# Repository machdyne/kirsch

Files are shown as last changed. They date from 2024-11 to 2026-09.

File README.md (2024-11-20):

# Kirsch Computer

Kirsch is an FPGA computer designed by Lone Dynamics Corporation.

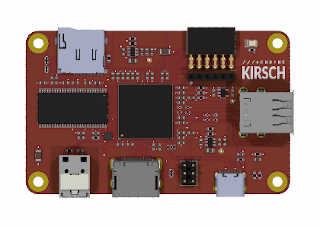
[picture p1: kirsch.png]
Kirsch Computer


This repo will contain schematics, PCB layouts, pinouts, a 3D-printable case, example gateware and documentation.

Find more information on the [Kirsch product page](https://machdyne.com/product/kirsch-computer/).

## Programming Kirsch

Kirsch has a JTAG interface that can be used to program the SRAM or the included flash [MMOD](https://machdyne.com/product/mmod).

### JTAG

These examples assume you're using a "USB Blaster" JTAG cable, see the header pinout below. You will need to have [openFPGALoader](https://github.com/trabucayre/openFPGALoader) installed.

Program the configuration SRAM:

```
openFPGALoader -c usb-blaster blinky.bit
```

Program the flash MMOD:

```
openFPGALoader -f -c usb-blaster blinky.bit --fpga-part xc7a35tftg256
```

## Blinky 

Building the blinky example requires Vivado or [openxc7](https://github.com/openxc7).

Assuming they are installed, you can simply type `make blinky_openxc7` or `make blinky_vivado` to build the gateware, which will be written to output/blinky.bit. You can then use [openFPGALoader](https://github.com/trabucayre/openFPGALoader) to write the gateware to the device.

## Linux

See the [Kakao Linux](https://github.com/machdyne/kakao) repo for the latest instructions.

### Prebuilt Images

Copy the files from the `images/linux` and `images/v0` directory to the root directory of a FAT-formatted MicroSD card along with the files from the `images` directory in the [Kakao Linux](https://github.com/machdyne/kakao) repo.

Kirsch ships with LiteX gateware on the user gateware section of the MMOD that is compatible with these images. After several seconds the Linux penguin should appear on the screen (HDMI) followed by a login prompt. A serial console is also available over the USB-C port.

**Note: If using the `kirsch_usbacm.bit` bitstream, Kirsch won't boot until you've opened a terminal program on the correct port. This is because DTR is currently used as a reset signal (see [valentyusb](https://github.com/litex-hub/valentyusb)). If you want to use Kirsch standalone, use `kirsch.bit` instead which uses the PMOD as a serial console.**

### Building Linux

Please follow the setup instructions in the [linux-on-litex-vexriscv](https://github.com/litex-hub/linux-on-litex-vexriscv) repo and then:

1. Build the Linux-capable gateware:

```
$ cd linux-on-litex-vexriscv
$ ./make.py --board kirsch --build
```

2. Write the gateware to the MMOD using USB DFU:

```
$ openFPGALoader -f -c usb-blaster build/kirsch/gateware/kirsch.bit --fpga-part xc7a35tftg256 
```
3. Copy the device tree binary `build/kirsch/kirsch.dtb` to a FAT-formatted MicroSD card.

4. Build the Linux kernel and root filesystem:

See the [Kakao Linux](https://github.com/machdyne/kakao?tab=readme-ov-file#optional-building-kakao-linux) repo for instructions.

5. Copy the Image and rootfs.cpio files generated in the previous step to the boot partition of the MicroSD card, in addition to the following files:

6. Copy the OpenSBI binary (included in this repo as `kirsch/images/linux/opensbi.bin`) to the MicroSD card. Alternatively, you can build this binary by following [these instructions](https://github.com/litex-hub/linux-on-litex-vexriscv#-generating-the-opensbi-binary-optional).

7. Copy `kirsch/images/linux/boot.json` to the MicroSD card.

8. Power-cycle Kirsch. After Linux has finished booting you should see a login prompt on the HDMI display.

## JTAG Header

The 3.3V JTAG header can be used to program the FPGA SRAM as well as the MMOD flash memory. It can also be used to provide power (5V) to the board.

```
1 2
3 4
5 6
```

| Pin | Signal |
| --- | --- |
| 1 | TCK |
| 2 | TDI |
| 3 | TDO |
| 4 | TMS |
| 5 | 5V0 |
| 6 | GND |

## Board Revisions

| Revision | Notes |
| --- | ----- |
| V0 | Initial version |

## License

The contents of this repo are released under the [Lone Dynamics Open License](LICENSE.md) with the following exceptions:

- The KiCad design files contain parts of the [kicad-pmod](https://github.com/mithro/kicad-pmod) library which is released under the [Apache License, Version 2.0](https://www.apache.org/licenses/LICENSE-2.0.html).

- The KiCad design files may contain symbols and footprints released under other licenses; please contact us if we've failed to give proper attribution.

Note: You can use these designs for commercial purposes but we ask that instead of producing exact clones, that you either replace our trademarks and logos with your own or add your own next to ours.

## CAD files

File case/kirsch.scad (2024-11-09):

/*
 * Kirsch Case
 * Copyright (c) 2024 Lone Dynamics Corporation. All rights reserved.
 *
 * required hardware:
 *  - 4 x M3 x 30mm countersunk bolts
 *  - 4 x M3 nuts
 *
 */

$fn = 100;

board_width = 52;
board_thickness = 1.5;
board_length = 84;
board_height = 1.6;
board_spacing = 2;

wall = 2;

top_height = 25;
bottom_height = 6;

translate([wall,wall,0]) mdx_board();

color([1,0,0]) translate([0,0,15])
	mdx_case_top();

color([1,0,0]) translate([0,0,-15])
	mdx_case_bottom();

translate([0,0,15])
	mdx_case_slide();

module mdx_board() {
	
	difference() {
		color([0,0.5,0])
			roundedcube(board_width,board_length,board_thickness,5);
		translate([4, 4, -1]) cylinder(d=3.2, h=10);
		translate([4, 84-4, -1]) cylinder(d=3.2, h=10);
		translate([52-4, 4, -1]) cylinder(d=3.2, h=10);
		translate([52-4, 84-4, -1]) cylinder(d=3.2, h=10);
	}	
	
}

module mdx_case_slide() {

	color([1,1,1]) translate([wall, wall, 0]) {
		difference() {
			union() {
				translate([-2,58.95-((25-0.2)/2),18]) cube([56,25-0.2,7]);
				translate([0,58.95-((27.5-0.4)/2),18]) cube([54,27.5-0.4,2.5-0.4]);
			}
			translate([-1,58.95-((22.5-0.2)/2),13.5]) cube([54,22.5-0.2,10]);
			translate([-2.5,58.95-(40/2),15+0.1]) cube([2.5,40,7]);
		}
	}
	
	
}

module mdx_case_top() {

	translate([0,25,19])
		rotate([90,0,270])
			translate([0,-10,0])
				linear_extrude(1)
					text("K I R S C H", size=5, halign="center",
						font="Liberation Sans:style=Bold");


	// supports
	translate([wall, wall, 0]) {
	}
	
	difference() {
				
		color([0.5,0.5,0.5])
			roundedcube(board_width+(wall*2),board_length+(wall*2),top_height,4);

		// cutouts
			
		translate([2,9.5,-2])
			roundedcube(board_width-1.25,board_length-16,20,5);

		translate([9.5,2,-2])
			roundedcube(board_width-16,board_length,20,5);			
	
		translate([wall, wall, 0]) {

			// vents
			translate([(52/2)-5,-5,10]) rotate([0,0,90]) cube([15,1,20]);
			translate([(52/2),-5,10]) rotate([0,0,90]) cube([15,1,20]);
			translate([(52/2)+5,-5,10]) rotate([0,0,90]) cube([15,1,20]);
			
			// USBC
			translate([30,65-(9.5/2),0]) cube([30,9.5,3.5]);

			// DDMI
			translate([30,35-(15.5/2),-1]) cube([30,15.5,6+1]);

			// AUDIO
			translate([30,15.5-(10/2),-1]) cube([30,10,10.5+1]);			
			
			// DUAL USBA
			translate([26-(15/2),80,0]) cube([15,10,15.8+1]);
	
			// SD
			translate([-10,17.6-(15/2),-2]) cube([15,15,2+2]);
			
			// PMODA
			translate([-10,58.95-(16/2),0]) cube([25,16,5.1]);

			// MMOD/JTAG ACCESS
			translate([0,58.95-(25/2),20]) cube([65,25,10+1]);
			translate([-4,58.95-(25/2),22]) cube([65,25,10+1]);
			translate([0,58.95-(27.5/2),18]) cube([65,27.5,2.5]);
			
			// bolt holes
			translate([4, 4, -15]) cylinder(d=3.5, h=40);
			translate([4, 84-4, -15]) cylinder(d=3.5, h=40);
			translate([52-4, 4, -14]) cylinder(d=3.5, h=40);
			translate([52-4, 84-4, -14]) cylinder(d=3.5, h=40);

			// flush mount bolt holes
			translate([4, 4, top_height-1.5]) cylinder(d=5.25, h=4);
			translate([4, 84-4, top_height-1.5]) cylinder(d=5.25, h=4);
			translate([52-4, 4, top_height-1.5]) cylinder(d=5.25, h=4);
			translate([52-4, 84-4, top_height-1.5]) cylinder(d=5.25, h=4);


		}
		
	}	
}

module mdx_case_bottom() {
	
	difference() {
		color([0.5,0.5,0.5])
			roundedcube(board_width+(wall*2),board_length+(wall*2),bottom_height,4);
		
		// cutouts
		translate([3,10,1.5])
			roundedcube(board_width-3,board_length-17,10,5);
				
		translate([10.5,3,1.5])
			roundedcube(board_width-17.5,board_length-2,10,5);

		translate([wall, wall, 0]) {
			
		// board cutout
		translate([0,0,bottom_height-board_height])
			roundedcube(board_width+0.2,board_length+0.2,board_height+1,2.5);

		// bolt holes
		translate([4, 4, -11]) cylinder(d=3.2, h=25);
		translate([4, 84-4, -11]) cylinder(d=3.2, h=25);
		translate([52-4, 4, -11]) cylinder(d=3.2, h=25);
		translate([52-4, 84-4, -11]) cylinder(d=3.2, h=25);

		// nut holes
		translate([4, 4, -1]) cylinder(d=7, h=4, $fn=6);
		translate([4, 84-4, -1]) cylinder(d=7, h=4, $fn=6);
		translate([52-4, 4, -1]) cylinder(d=7, h=4, $fn=6);
		translate([52-4, 84-4, -1]) cylinder(d=7, h=4, $fn=6);

		}
		
	}	
}

// https://gist.github.com/tinkerology/ae257c5340a33ee2f149ff3ae97d9826
module roundedcube(xx, yy, height, radius)
{
    translate([0,0,height/2])
    hull()
    {
        translate([radius,radius,0])
        cylinder(height,radius,radius,true);

        translate([xx-radius,radius,0])
        cylinder(height,radius,radius,true);

        translate([xx-radius,yy-radius,0])
        cylinder(height,radius,radius,true);

        translate([radius,yy-radius,0])
        cylinder(height,radius,radius,true);
    }
}

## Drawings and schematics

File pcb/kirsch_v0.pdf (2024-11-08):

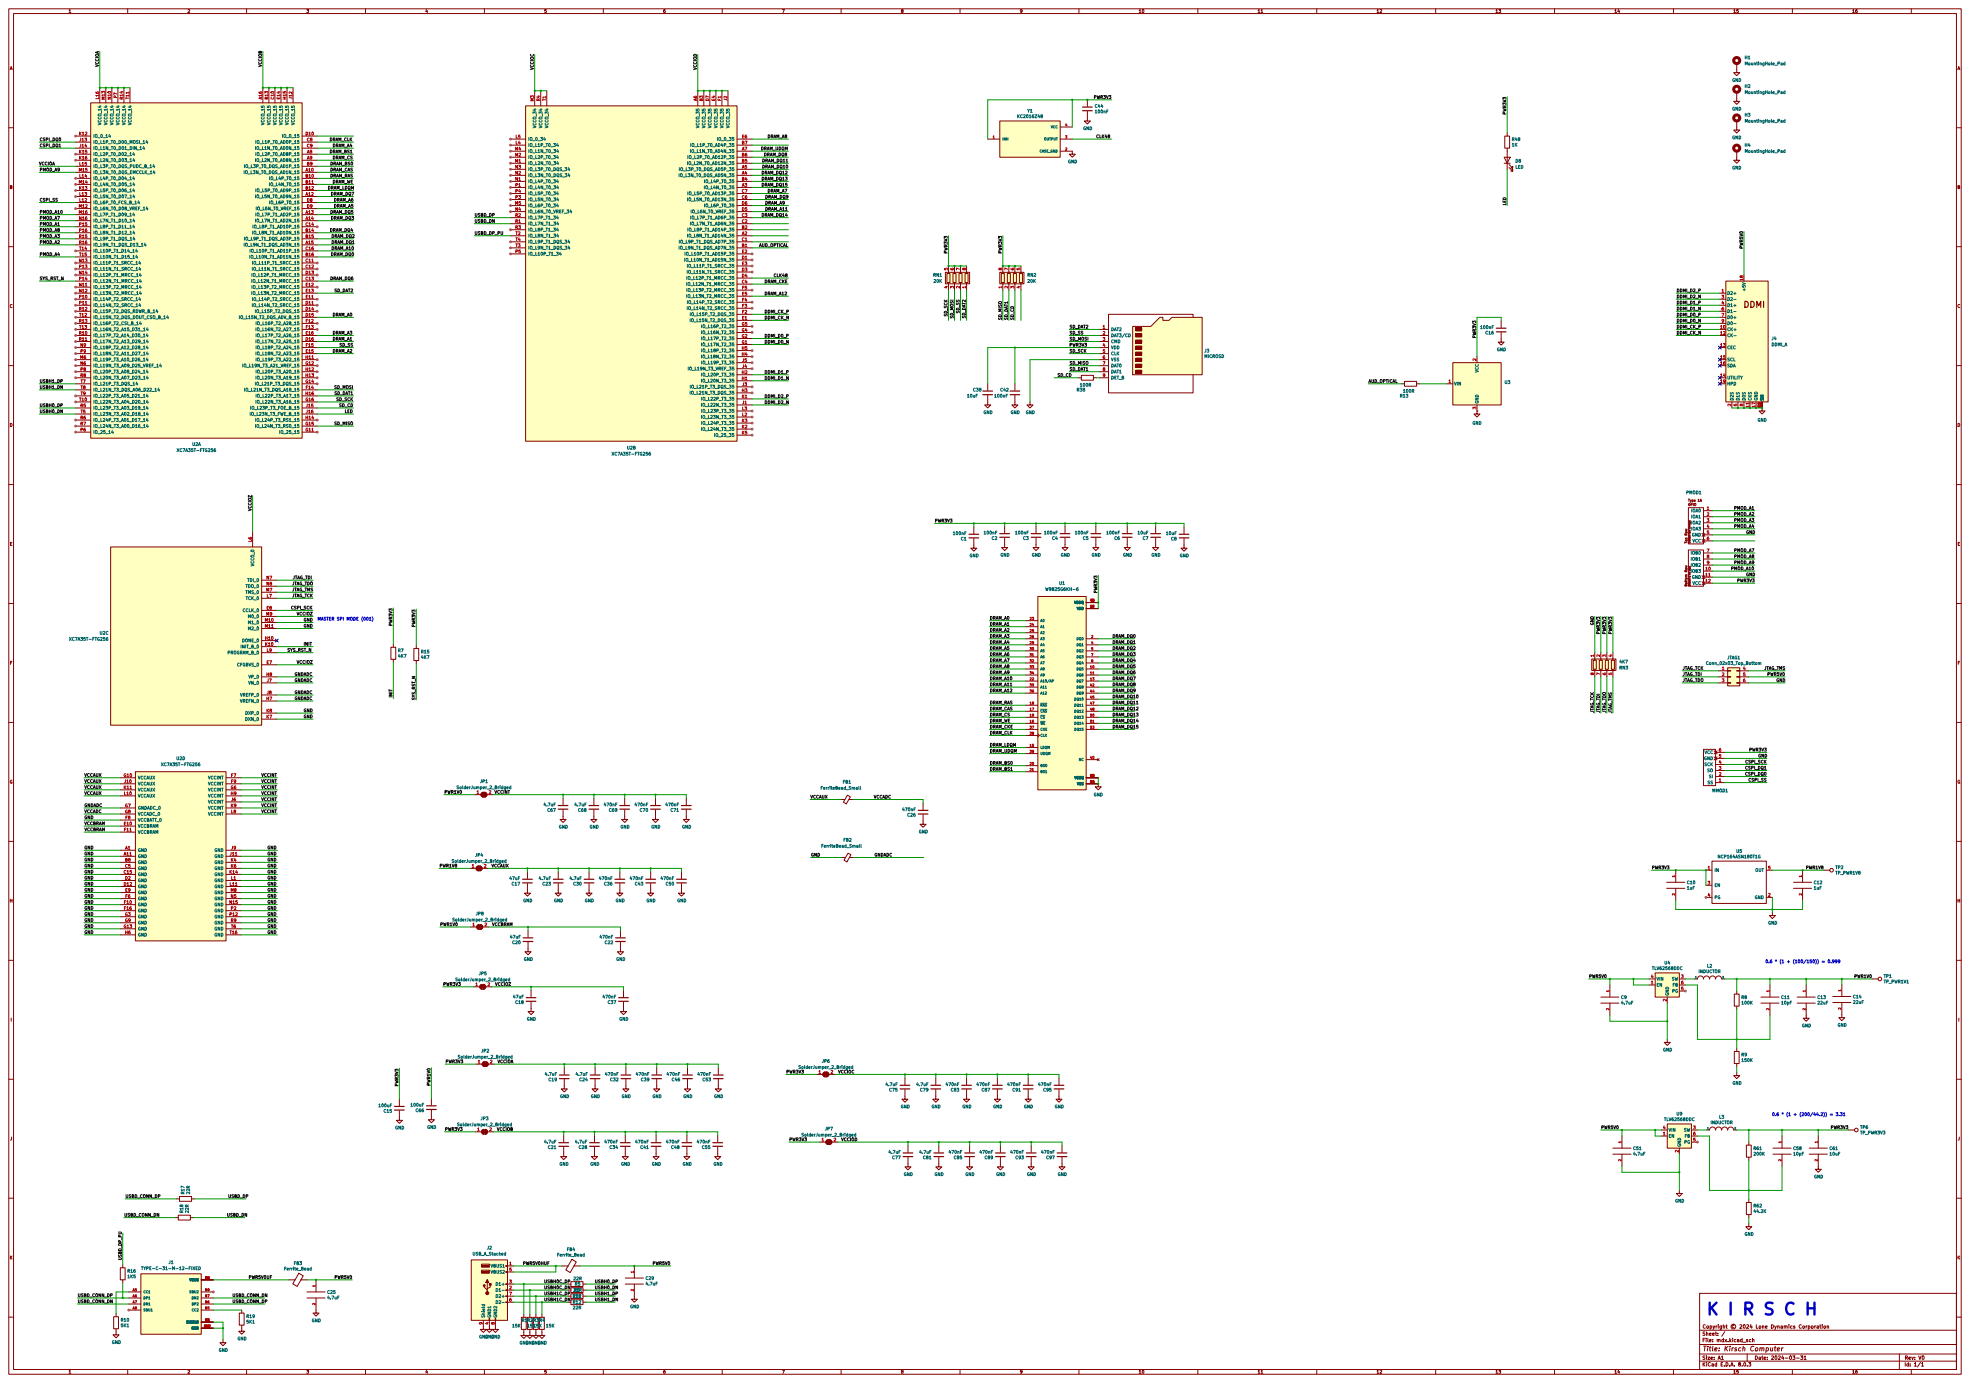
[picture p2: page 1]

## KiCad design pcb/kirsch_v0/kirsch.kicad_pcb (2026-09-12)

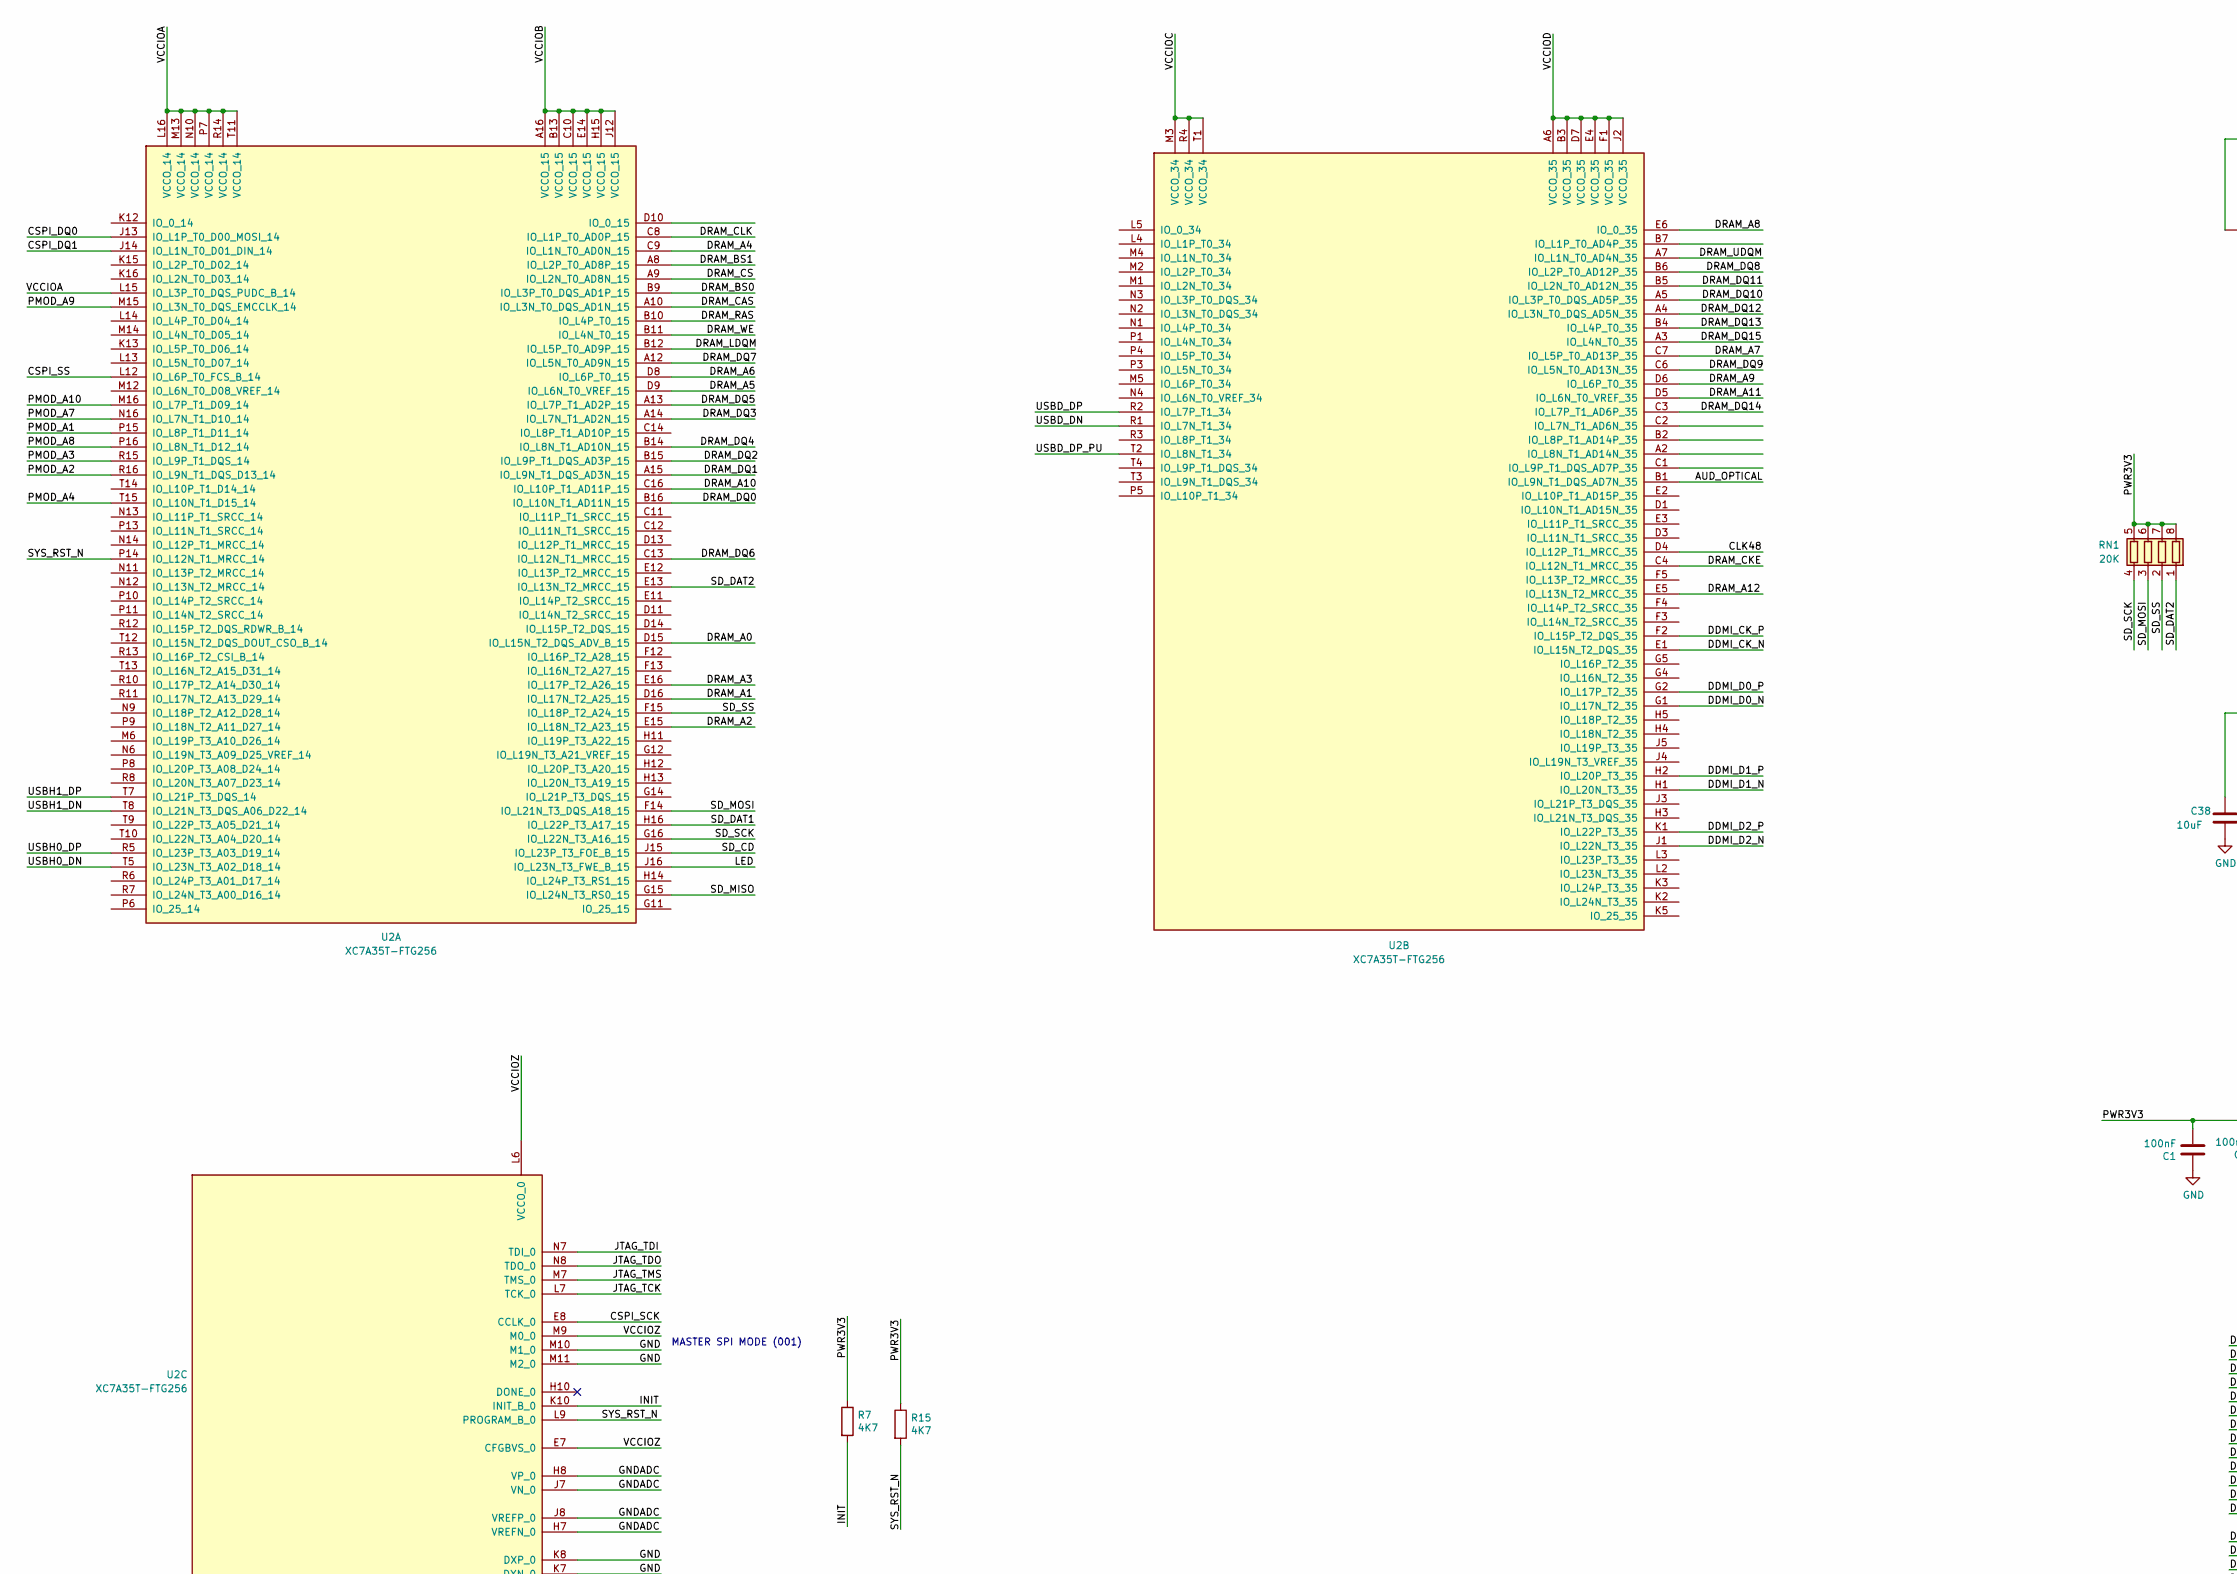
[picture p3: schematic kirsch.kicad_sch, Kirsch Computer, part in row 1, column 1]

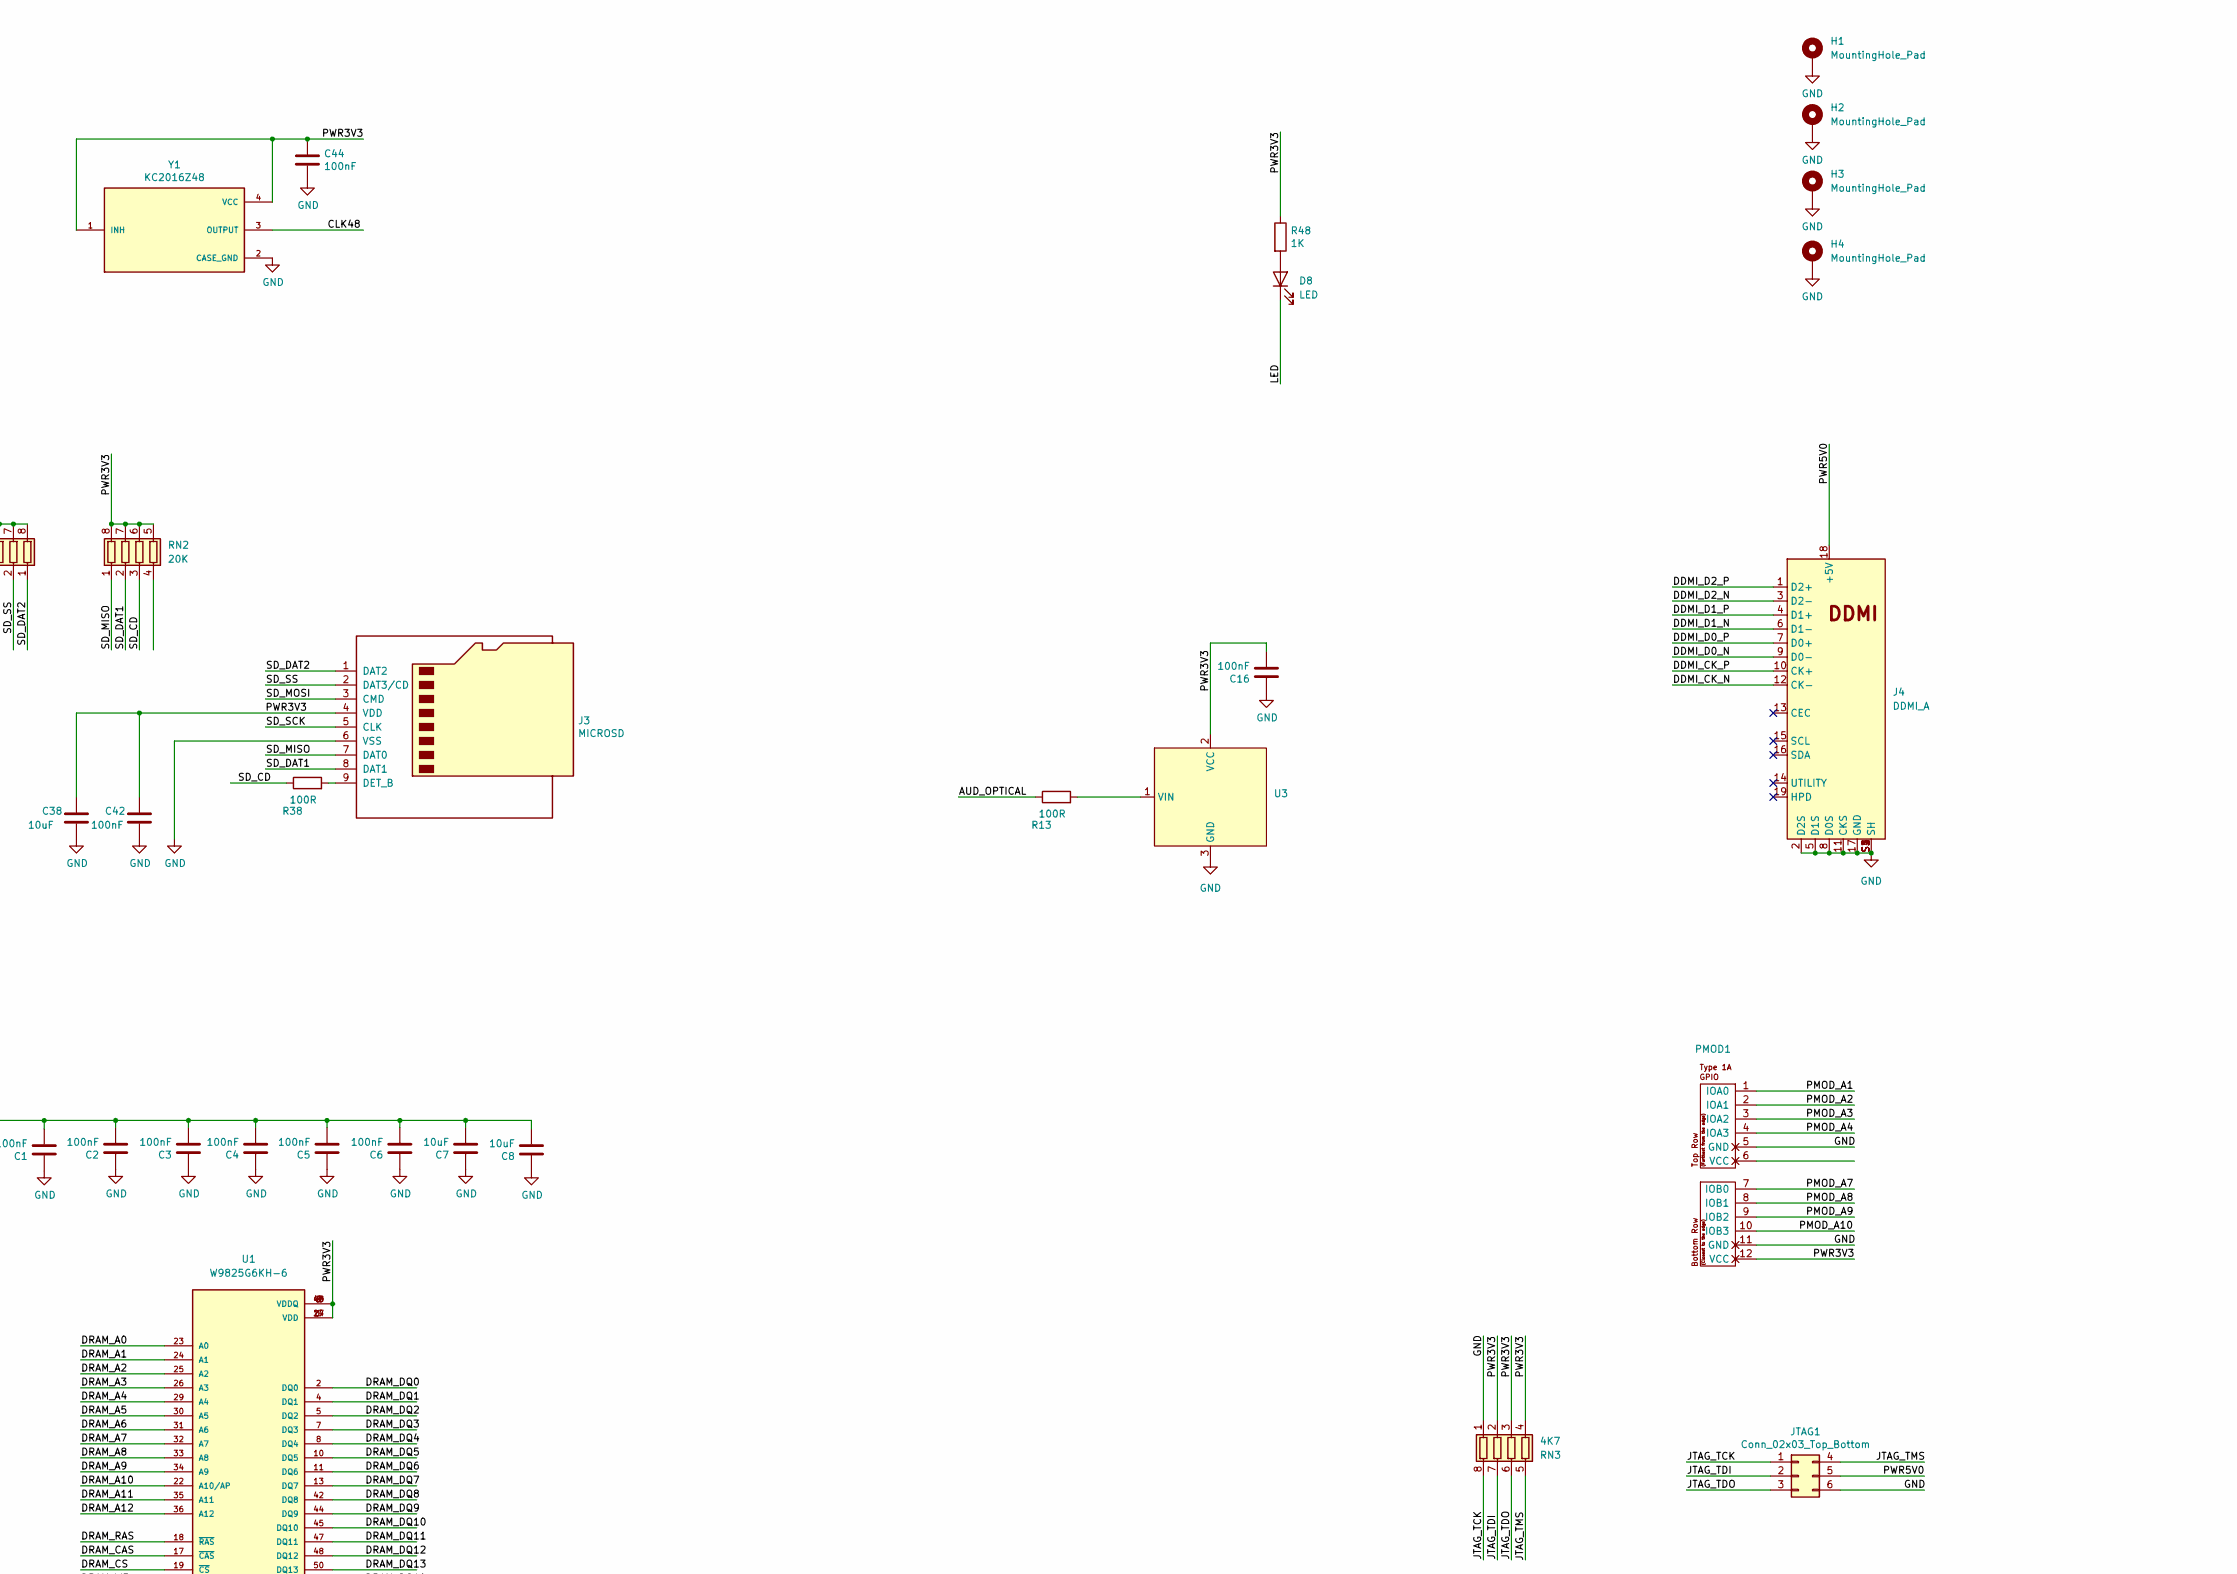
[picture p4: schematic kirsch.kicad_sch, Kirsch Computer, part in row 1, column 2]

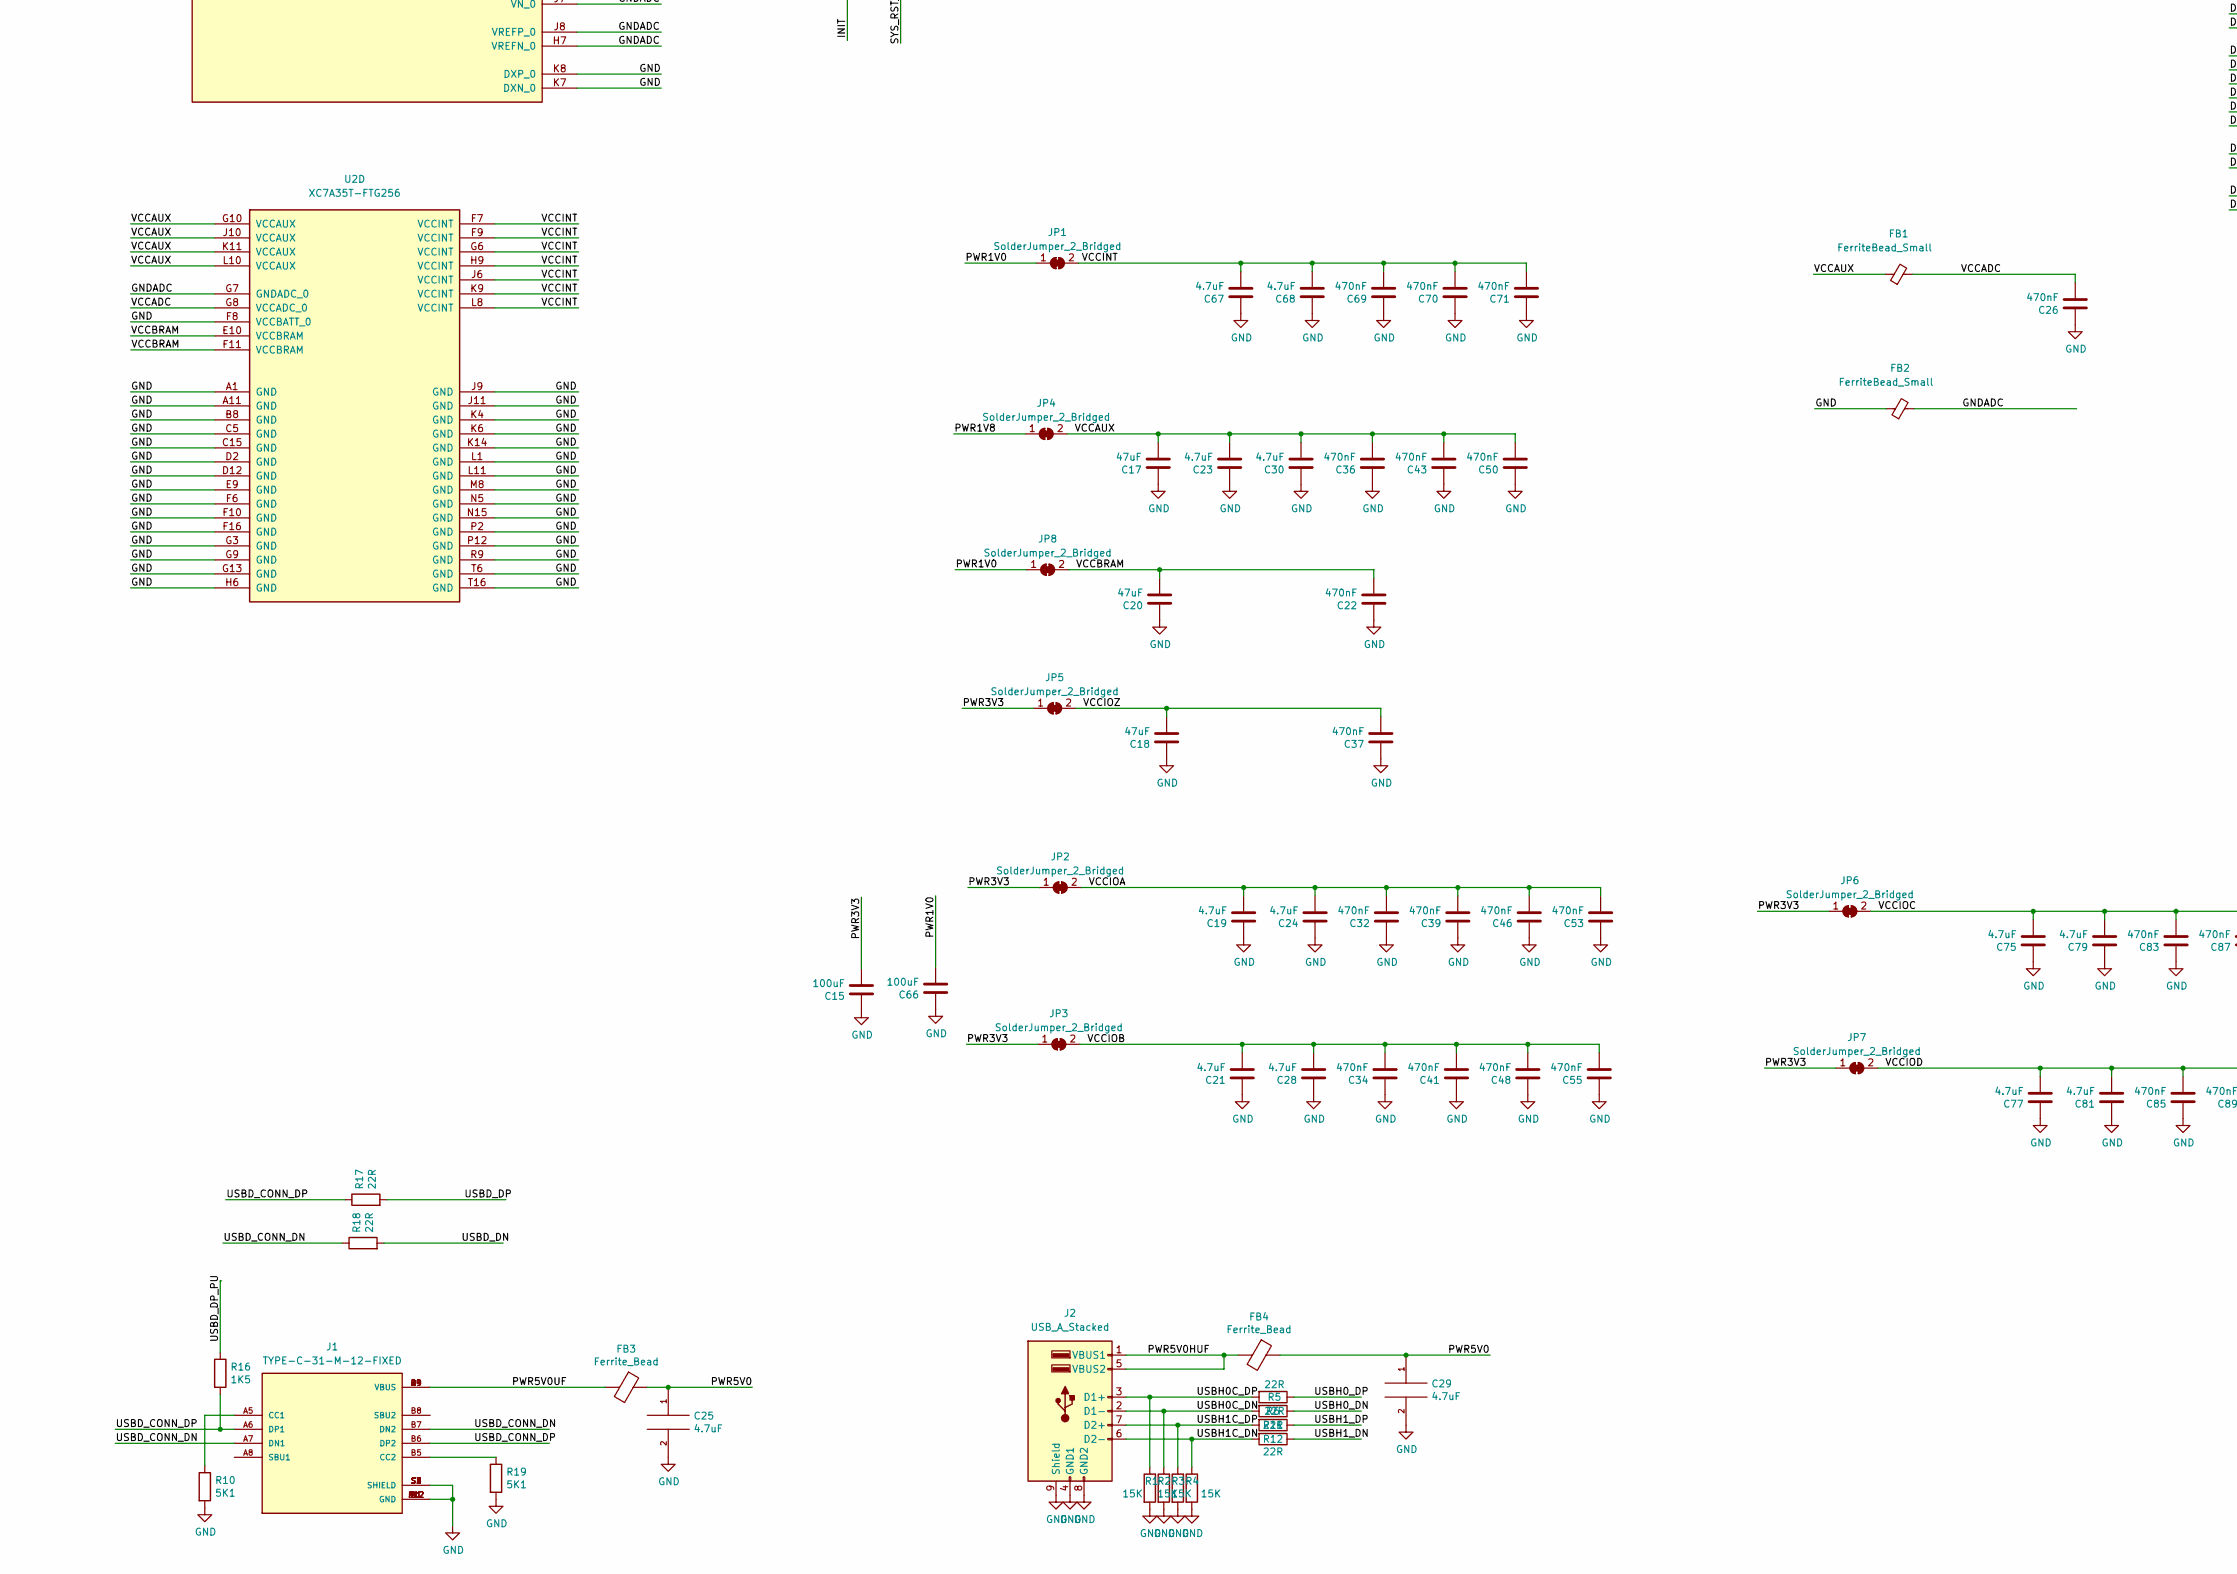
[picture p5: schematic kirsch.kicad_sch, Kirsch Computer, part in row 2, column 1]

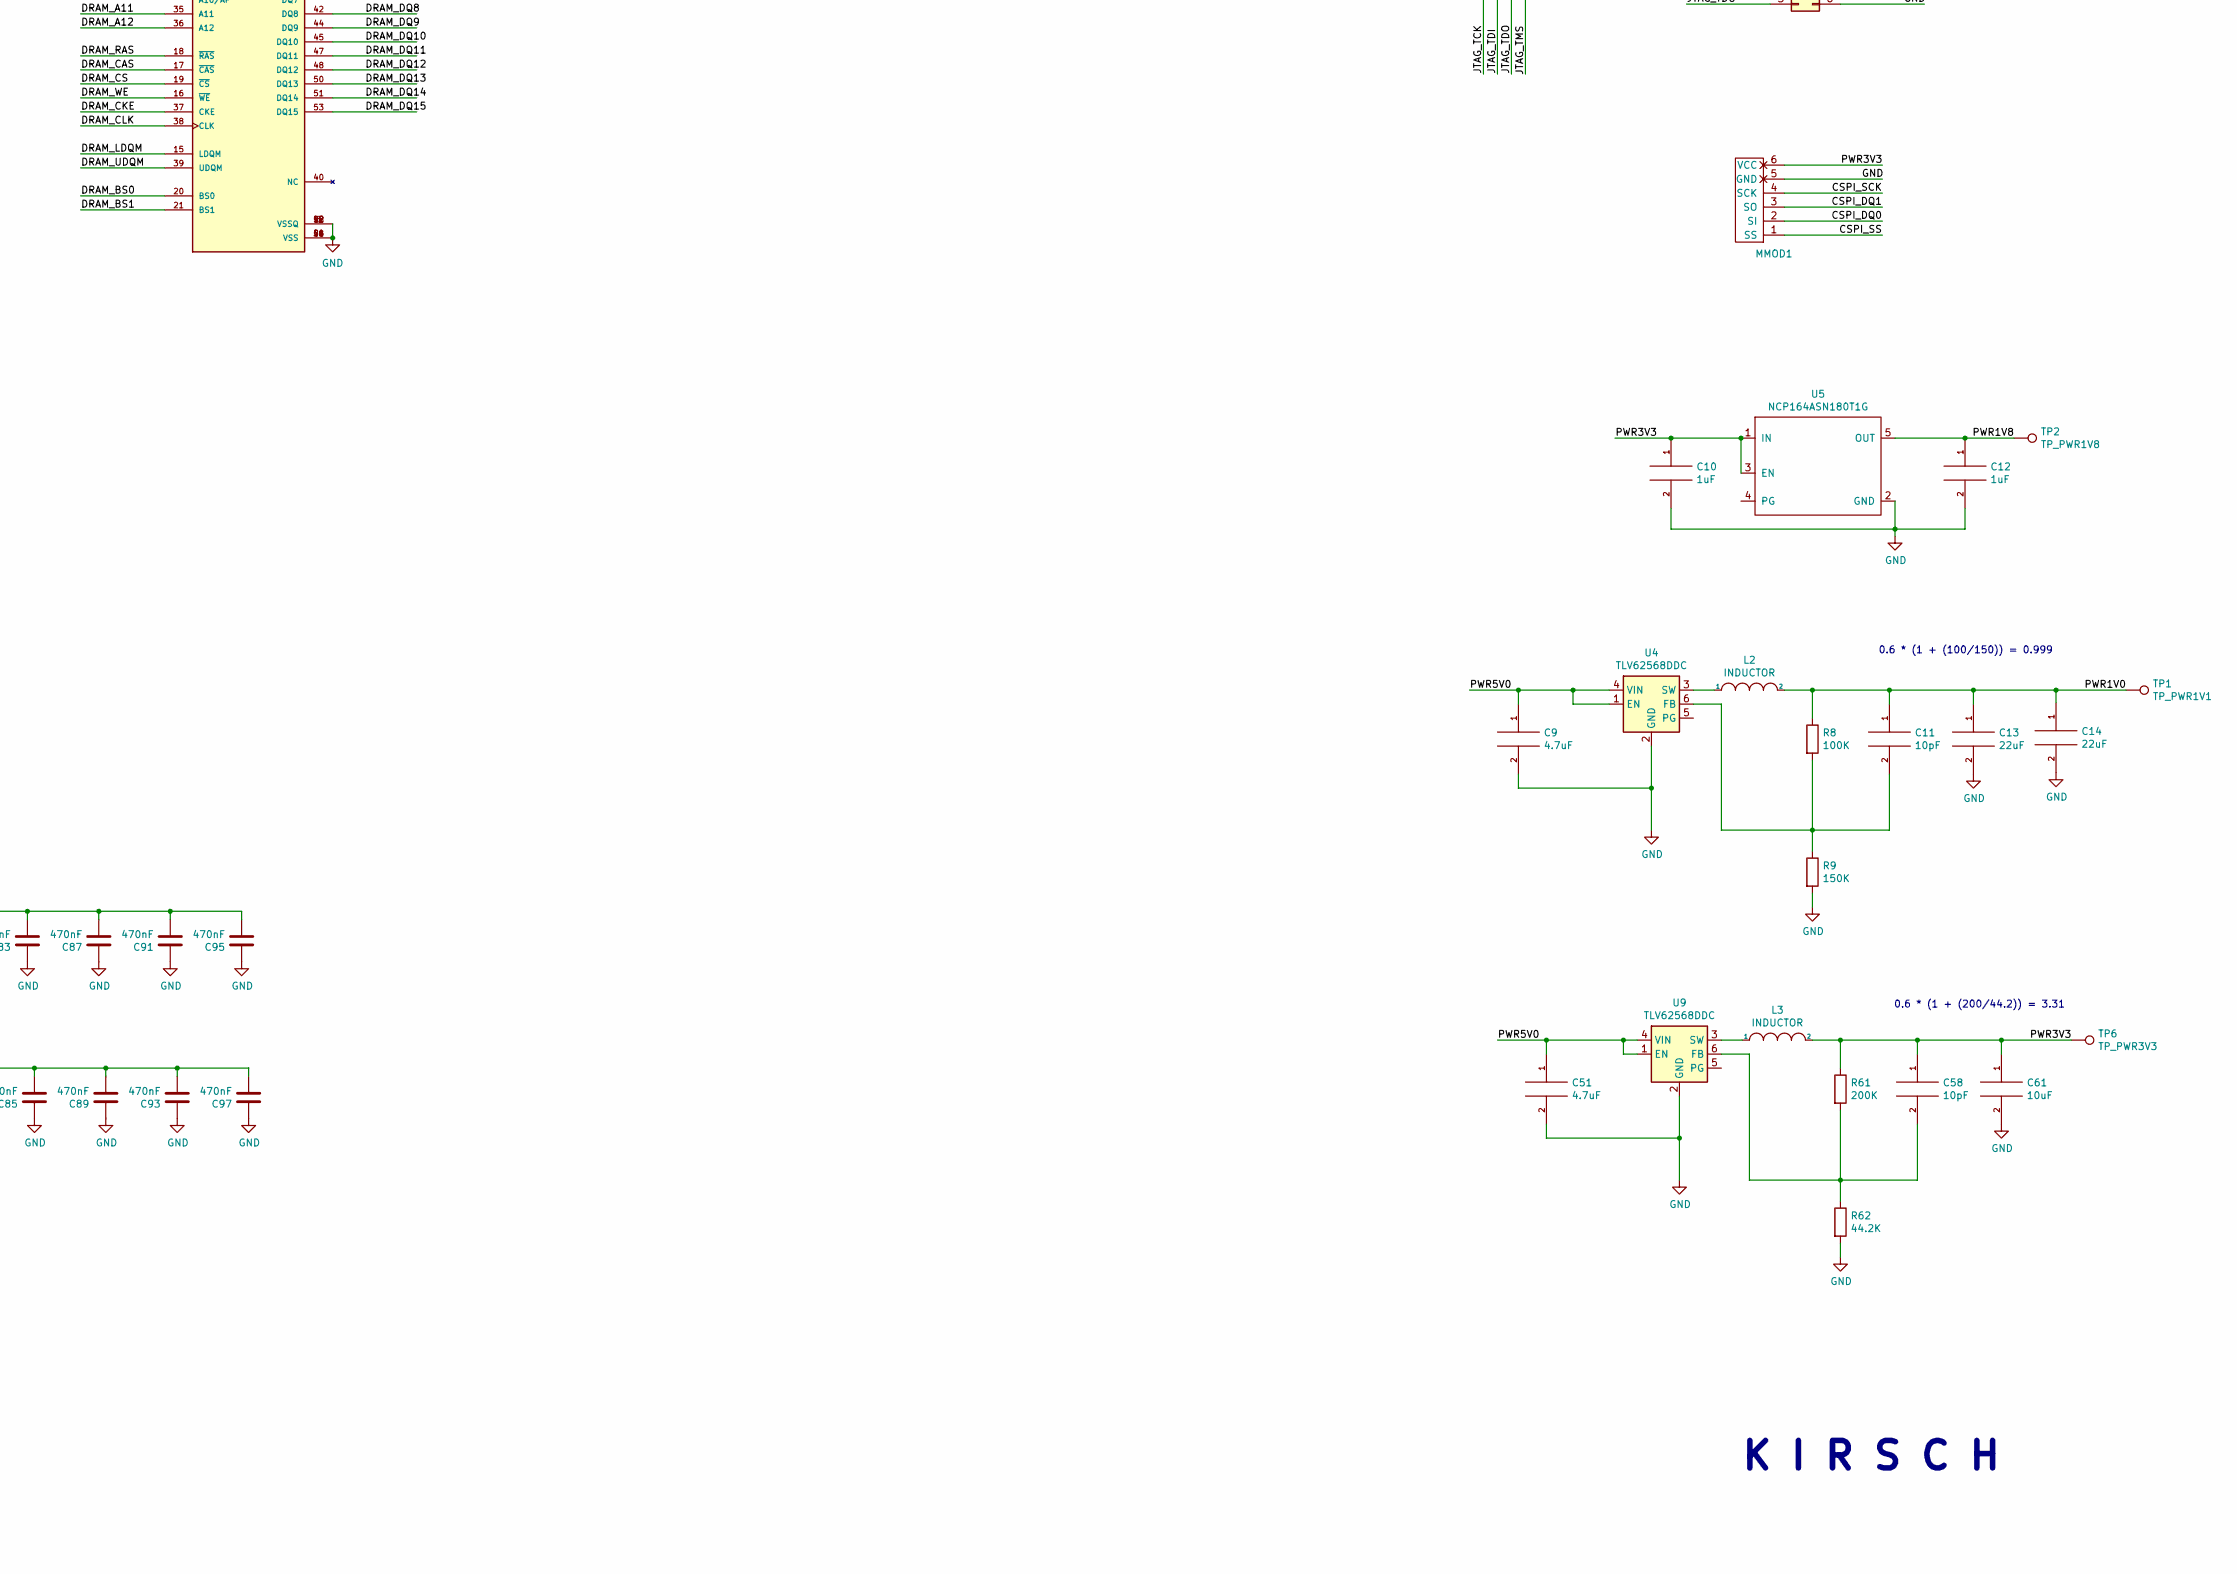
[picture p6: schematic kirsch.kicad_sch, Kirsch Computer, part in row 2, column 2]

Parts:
C1, C2, C3, C4, C5, C6, C16, C42: 100nF; C_0603_1608Metric
C7, C8, C38, C61: 10uF; C_0603_1608Metric
C9, C19, C21, C23, C24, C25, C28, C29, C30, C51, C67, C68, C75, C77, C79, C81: 4.7uF; C_0603_1608Metric
C10, C12: 1uF; C_0603_1608Metric
C11, C58: 10pF; C_0603_1608Metric
C13, C14: 22uF; C_0603_1608Metric
C15, C66: 100uF; C_1206_3216Metric
C17, C18, C20: 47uF; C_0603_1608Metric
C22, C32, C34, C39, C41, C46, C83, C85, C87, C93: 470nF; C_0603_1608Metric
C26, C36, C37, C43, C48, C50, C53, C55, C69, C70, C71, C89, C91, C95, C97: 470nF; C_0402_1005Metric
C44: 100nF; R_0603_1608Metric
D8: LED; LED_1206_3216Metric
FB1, FB2: FerriteBead_Small; L_0402_1005Metric
FB3, FB4: Ferrite_Bead; R_0603_1608Metric
H1, H2, H3, H4: MountingHole_Pad; MountingHole_3.2mm_M3_Pad
J1: TYPE-C-31-M-12-FIXED; USB_C_Receptacle_HRO_TYPE-C-31-M-12-BIG-PADS; PARTREV A
J2: USB_A_Stacked; USB_A_Wuerth_61400826021_Horizontal_Stacked
J3: MICROSD; SDCARD
J4: DDMI_A; HDMI_TE_1827059-3-FIXED
JP1, JP2, JP3, JP4, JP5, JP6, JP7, JP8: SolderJumper_2_Bridged; LD-NETTIE-0603
JTAG1: Conn_02x03_Top_Bottom; PinHeader_2x03_P2.54mm_Vertical
L2, L3: INDUCTOR; L_0805_2012Metric
MMOD1: PMOD-Device-x1-Type-2-SPI; MMOD_Host_Socket_Vertical
PMOD1: PMOD-Device-x2-Type-1A-GPIO; PMOD_2x06_HOST
R1, R2, R3, R4: 15K; R_0402_1005Metric
R5, R6, R11, R12, R17, R18: 22R; R_0402_1005Metric
R7, R15: 4K7; R_0603_1608Metric
R8: 100K; R_0603_1608Metric
R9: 150K; R_0603_1608Metric
R10, R19: 5K1; R_0603_1608Metric
R13, R38: 100R; R_0603_1608Metric
R16: 1K5; R_0402_1005Metric
R48: 1K; R_0603_1608Metric
R61: 200K; R_0603_1608Metric
R62: 44.2K; R_0603_1608Metric
RN1, RN2: 20K; R_Array_Convex_4x0402
RN3: 4K7; R_Array_Convex_4x0402
TP1: TP_PWR1V1; TestPoint_THTPad_D1.0mm_Drill0.5mm
TP2: TP_PWR1V8; TestPoint_THTPad_D1.0mm_Drill0.5mm
TP6: TP_PWR3V3; TestPoint_THTPad_D1.0mm_Drill0.5mm
U1: W9825G6KH-6; SOP80P1176X120-54N; PARTREV A05
U2: XC7A35T-FTG256; BGA-256_17.0x17.0mm_Layout16x16_P1.0mm_Ball0.5mm_Pad0.5mm_N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
U3: ZGY133
U4, U9: TLV62568DDC; SOT-23-6
U5: NCP164ASN180T1G; SOT-23-5
Y1: KC2016Z48; OSC_KC2016Z13.5600C1KX00; PARTREV November 2020

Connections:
/AUD_OPTICAL: R13.1, U2.B1 (IO_L9N_T1_DQS_AD7N_35)
/CLK48: U2.D4 (IO_L12P_T1_MRCC_35), Y1.3 (OUTPUT)
/CSPI_DQ0: MMOD1.2 (SI), U2.J13 (IO_L1P_T0_D00_MOSI_14)
/CSPI_DQ1: MMOD1.3 (SO), U2.J14 (IO_L1N_T0_D01_DIN_14)
/CSPI_SCK: MMOD1.4 (SCK), U2.E8 (CCLK_0)
/CSPI_SS: MMOD1.1 (SS), U2.L12 (IO_L6P_T0_FCS_B_14); also elsewhere on the board
/DDMI_CK_N: J4.12 (CK-), U2.E1 (IO_L15N_T2_DQS_35)
/DDMI_CK_P: J4.10 (CK+), U2.F2 (IO_L15P_T2_DQS_35)
/DDMI_D0_N: J4.9 (D0-), U2.G1 (IO_L17N_T2_35)
/DDMI_D0_P: J4.7 (D0+), U2.G2 (IO_L17P_T2_35)
/DDMI_D1_N: J4.6 (D1-), U2.H1 (IO_L20N_T3_35)
/DDMI_D1_P: J4.4 (D1+), U2.H2 (IO_L20P_T3_35)
/DDMI_D2_N: J4.3 (D2-), U2.J1 (IO_L22N_T3_35)
/DDMI_D2_P: J4.1 (D2+), U2.K1 (IO_L22P_T3_35)
/DRAM_A0: U1.23 (A0), U2.D15 (IO_L15N_T2_DQS_ADV_B_15)
/DRAM_A1: U1.24 (A1), U2.D16 (IO_L17N_T2_A25_15)
/DRAM_A2: U1.25 (A2), U2.E15 (IO_L18N_T2_A23_15)
/DRAM_A3: U1.26 (A3), U2.E16 (IO_L17P_T2_A26_15)
/DRAM_A4: U1.29 (A4), U2.C9 (IO_L1N_T0_AD0N_15)
/DRAM_A5: U1.30 (A5), U2.D9 (IO_L6N_T0_VREF_15)
/DRAM_A6: U1.31 (A6), U2.D8 (IO_L6P_T0_15)
/DRAM_A7: U1.32 (A7), U2.C7 (IO_L5P_T0_AD13P_35)
/DRAM_A8: U1.33 (A8), U2.E6 (IO_0_35)
/DRAM_A9: U1.34 (A9), U2.D6 (IO_L6P_T0_35)
/DRAM_A10: U1.22 (A10/AP), U2.C16 (IO_L10P_T1_AD11P_15)
/DRAM_A11: U1.35 (A11), U2.D5 (IO_L6N_T0_VREF_35)
/DRAM_A12: U1.36 (A12), U2.E5 (IO_L13N_T2_MRCC_35)
/DRAM_BS0: U1.20 (BS0), U2.B9 (IO_L3P_T0_DQS_AD1P_15)
/DRAM_BS1: U1.21 (BS1), U2.A8 (IO_L2P_T0_AD8P_15)
/DRAM_CAS: U1.17 (~CAS), U2.A10 (IO_L3N_T0_DQS_AD1N_15)
/DRAM_CKE: U1.37 (CKE), U2.C4 (IO_L12N_T1_MRCC_35)
/DRAM_CLK: U1.38 (CLK), U2.C8 (IO_L1P_T0_AD0P_15)
/DRAM_CS: U1.19 (~CS), U2.A9 (IO_L2N_T0_AD8N_15)
/DRAM_DQ0: U1.2 (DQ0), U2.B16 (IO_L10N_T1_AD11N_15)
/DRAM_DQ1: U1.4 (DQ1), U2.A15 (IO_L9N_T1_DQS_AD3N_15)
/DRAM_DQ2: U1.5 (DQ2), U2.B15 (IO_L9P_T1_DQS_AD3P_15)
/DRAM_DQ3: U1.7 (DQ3), U2.A14 (IO_L7N_T1_AD2N_15)
/DRAM_DQ4: U1.8 (DQ4), U2.B14 (IO_L8N_T1_AD10N_15)
/DRAM_DQ5: U1.10 (DQ5), U2.A13 (IO_L7P_T1_AD2P_15)
/DRAM_DQ6: U1.11 (DQ6), U2.C13 (IO_L12N_T1_MRCC_15)
/DRAM_DQ7: U1.13 (DQ7), U2.A12 (IO_L5N_T0_AD9N_15)
/DRAM_DQ8: U1.42 (DQ8), U2.B6 (IO_L2P_T0_AD12P_35)
/DRAM_DQ9: U1.44 (DQ9), U2.C6 (IO_L5N_T0_AD13N_35)
/DRAM_DQ10: U1.45 (DQ10), U2.A5 (IO_L3P_T0_DQS_AD5P_35)
/DRAM_DQ11: U1.47 (DQ11), U2.B5 (IO_L2N_T0_AD12N_35)
/DRAM_DQ12: U1.48 (DQ12), U2.A4 (IO_L3N_T0_DQS_AD5N_35)
/DRAM_DQ13: U1.50 (DQ13), U2.B4 (IO_L4P_T0_35)
/DRAM_DQ14: U1.51 (DQ14), U2.C3 (IO_L7P_T1_AD6P_35)
/DRAM_DQ15: U1.53 (DQ15), U2.A3 (IO_L4N_T0_35)
/DRAM_LDQM: U1.15 (LDQM), U2.B12 (IO_L5P_T0_AD9P_15)
/DRAM_RAS: U1.18 (~RAS), U2.B10 (IO_L4P_T0_15)
/DRAM_UDQM: U1.39 (UDQM), U2.A7 (IO_L1N_T0_AD4N_35)
/DRAM_WE: U1.16 (~WE), U2.B11 (IO_L4N_T0_15)
/ETH_RST_N: U2.H4 (IO_L18N_T2_35)
/GNDADC: FB2.2, U2.G7 (GNDADC_0), U2.H7 (VREFN_0), U2.H8 (VP_0), U2.J7 (VN_0), U2.J8 (VREFP_0)
/INIT: R7.2, U2.K10 (INIT_B_0)
/JTAG_TCK: JTAG1.1, RN3.8 (R1.2), U2.L7 (TCK_0)
/JTAG_TDI: JTAG1.2, RN3.7 (R2.2), U2.N7 (TDI_0)
/JTAG_TDO: JTAG1.3, RN3.6 (R3.2), U2.N8 (TDO_0)
/JTAG_TMS: JTAG1.4, RN3.5 (R4.2), U2.M7 (TMS_0)
/LED: D8.1 (K), U2.J16 (IO_L23N_T3_FWE_B_15)
/PMOD_A1: PMOD1.1 (IOA0), U2.P15 (IO_L8P_T1_D11_14)
/PMOD_A2: PMOD1.2 (IOA1), U2.R16 (IO_L9N_T1_DQS_D13_14)
/PMOD_A3: PMOD1.3 (IOA2), U2.R15 (IO_L9P_T1_DQS_14)
/PMOD_A4: PMOD1.4 (IOA3), U2.T15 (IO_L10N_T1_D15_14)
/PMOD_A7: PMOD1.7 (IOB0), U2.N16 (IO_L7N_T1_D10_14)
/PMOD_A8: PMOD1.8 (IOB1), U2.P16 (IO_L8N_T1_D12_14)
/PMOD_A9: PMOD1.9 (IOB2), U2.M15 (IO_L3N_T0_DQS_EMCCLK_14)
/PMOD_A10: PMOD1.10 (IOB3), U2.M16 (IO_L7P_T1_D09_14)
/PWR1V0: C11.1, C13.1, C14.1, C66.2, JP1.1 (A), JP8.1 (A), L2.2, R8.1, TP1.1
/PWR1V8: C12.1, JP4.1 (A), TP2.1, U5.5 (OUT)
/PWR3V3: C1.2, C2.2, C3.2, C4.2, C5.2, C6.2, C7.2, C8.2, C10.1, C15.2, C16.2, C38.1, C42.1, C44.1, C58.1, C61.1, J3.4 (VDD), JP2.1 (A), JP3.1 (A), JP5.1 (A), JP6.1 (A), JP7.1 (A), L3.2, MMOD1.6 (VCC), PMOD1.12 (VCC), R7.1, R15.1, R48.1, R61.1, RN1.5 (R4.2), RN1.6 (R3.2), RN1.7 (R2.2), RN1.8 (R1.2), RN2.5 (R4.2), RN2.6 (R3.2), RN2.7 (R2.2), RN2.8 (R1.2), RN3.2 (R2.1), RN3.3 (R3.1), RN3.4 (R4.1), TP6.1, U1.1 (VDD), U1.3 (VDDQ), U1.9 (VDDQ), U1.14 (VDD), U1.27 (VDD), U1.43 (VDDQ), U1.49 (VDDQ), U3.2 (VCC), U5.1 (IN), U5.3 (EN), Y1.1 (INH), Y1.4 (VCC); also elsewhere on the board
/PWR5V0: C9.1, C25.1, C29.1, C51.1, FB3.1, FB4.1, J4.18 (+5V), JTAG1.5, U4.1 (EN), U4.4 (VIN), U9.1 (EN), U9.4 (VIN)
/PWR5V0HUF: FB4.2, J2.1 (VBUS1), J2.5 (VBUS2)
/PWR5V0UF: FB3.2, J1.A4 (VBUS), J1.A9 (VBUS), J1.B4 (VBUS), J1.B9 (VBUS)
/SD_CD: R38.1, RN2.3 (R3.1), U2.J15 (IO_L23P_T3_FOE_B_15)
/SD_DAT1: J3.8 (DAT1), RN2.2 (R2.1), U2.H16 (IO_L22P_T3_A17_15)
/SD_DAT2: J3.1 (DAT2), RN1.1 (R1.1), U2.E13 (IO_L13N_T2_MRCC_15)
/SD_MISO: J3.7 (DAT0), RN2.1 (R1.1), U2.G15 (IO_L24N_T3_RS0_15)
/SD_MOSI: J3.3 (CMD), RN1.3 (R3.1), U2.F14 (IO_L21N_T3_DQS_A18_15)
/SD_SCK: J3.5 (CLK), RN1.4 (R4.1), U2.G16 (IO_L22N_T3_A16_15)
/SD_SS: J3.2 (DAT3/CD), RN1.2 (R2.1), U2.F15 (IO_L18P_T2_A24_15)
/SYS_RST_N: R15.2, U2.L9 (PROGRAM_B_0), U2.P14 (IO_L12N_T1_MRCC_14)
/USBD_CONN_DN: J1.A7 (DN1), J1.B7 (DN2), R18.1
/USBD_CONN_DP: J1.A6 (DP1), J1.B6 (DP2), R16.2, R17.1
/USBD_DN: R18.2, U2.R1 (IO_L7N_T1_34)
/USBD_DP: R17.2, U2.R2 (IO_L7P_T1_34)
/USBD_DP_PU: R16.1, U2.T2 (IO_L8N_T1_34)
/USBH0C_DN: J2.2 (D1-), R2.1, R6.2
/USBH0C_DP: J2.3 (D1+), R1.1, R5.2
/USBH0_DN: R6.1, U2.T5 (IO_L23N_T3_A02_D18_14)
/USBH0_DP: R5.1, U2.R5 (IO_L23P_T3_A03_D19_14)
/USBH1C_DN: J2.6 (D2-), R4.1, R12.2
/USBH1C_DP: J2.7 (D2+), R3.1, R11.2
/USBH1_DN: R12.1, U2.T8 (IO_L21N_T3_DQS_A06_D22_14)
/USBH1_DP: R11.1, U2.T7 (IO_L21P_T3_DQS_14)
/VCCADC: C26.2, FB1.2, U2.G8 (VCCADC_0)
/VCCAUX: C17.2, C23.2, C30.2, C36.2, C43.2, C50.2, FB1.1, JP4.2 (B), U2.G10 (VCCAUX), U2.J10 (VCCAUX), U2.K11 (VCCAUX), U2.L10 (VCCAUX)
/VCCBRAM: C20.2, C22.2, JP8.2 (B), U2.E10 (VCCBRAM), U2.F11 (VCCBRAM)
/VCCINT: C67.2, C68.2, C69.2, C70.2, C71.2, JP1.2 (B), U2.F7 (VCCINT), U2.F9 (VCCINT), U2.G6 (VCCINT), U2.H9 (VCCINT), U2.J6 (VCCINT), U2.K9 (VCCINT), U2.L8 (VCCINT)
/VCCIOA: C19.2, C24.2, C32.2, C39.2, C46.2, C53.2, JP2.2 (B), U2.L15 (IO_L3P_T0_DQS_PUDC_B_14), U2.L16 (VCCO_14), U2.M13 (VCCO_14), U2.N10 (VCCO_14), U2.P7 (VCCO_14), U2.R14 (VCCO_14), U2.T11 (VCCO_14)
/VCCIOB: C21.2, C28.2, C34.2, C41.2, C48.2, C55.2, JP3.2 (B), U2.A16 (VCCO_15), U2.B13 (VCCO_15), U2.C10 (VCCO_15), U2.E14 (VCCO_15), U2.H15 (VCCO_15), U2.J12 (VCCO_15)
/VCCIOC: C75.2, C79.2, C83.2, C87.2, C91.2, C95.2, JP6.2 (B), U2.M3 (VCCO_34), U2.R4 (VCCO_34), U2.T1 (VCCO_34)
/VCCIOD: C77.2, C81.2, C85.2, C89.2, C93.2, C97.2, JP7.2 (B), U2.A6 (VCCO_35), U2.B3 (VCCO_35), U2.D7 (VCCO_35), U2.E4 (VCCO_35), U2.F1 (VCCO_35), U2.J2 (VCCO_35)
/VCCIOZ: C18.2, C37.2, JP5.2 (B), U2.E7 (CFGBVS_0), U2.L6 (VCCO_0), U2.M9 (M0_0)
GND: C1.1, C2.1, C3.1, C4.1, C5.1, C6.1, C7.1, C8.1, C9.2, C10.2, C12.2, C13.2, C14.2, C15.1, C16.1, C17.1, C18.1, C19.1, C20.1, C21.1, C22.1, C23.1, C24.1, C25.2, C26.1, C28.1, C29.2, C30.1, C32.1, C34.1, C36.1, C37.1, C38.2, C39.1, C41.1, C42.2, C43.1, C44.2, C46.1, C48.1, C50.1, C51.2, C53.1, C55.1, C61.2, C66.1, C67.1, C68.1, C69.1, C70.1, C71.1, C75.1, C77.1, C79.1, C81.1, C83.1, C85.1, C87.1, C89.1, C91.1, C93.1, C95.1, C97.1, FB2.1, H1.1, H2.1, H3.1, H4.1, J1.A1 (GND), J1.A12 (GND), J1.B1 (GND), J1.B12 (GND), J1.S1 (SHIELD), J1.S2 (SHIELD), J1.S3 (SHIELD), J1.S4 (SHIELD), J2.4 (GND1), J2.8 (GND2), J2.9 (Shield), J3.6 (VSS), J4.2 (D2S), J4.5 (D1S), J4.8 (D0S), J4.11 (CKS), J4.17 (GND), J4.S1 (SH), J4.S2 (SH), J4.S3 (SH), J4.S4 (SH), JTAG1.6, MMOD1.5 (GND), PMOD1.5 (GND), PMOD1.11 (GND), R1.2, R2.2, R3.2, R4.2, R9.2, R10.2, R19.2, R62.2, RN3.1 (R1.1), U1.6 (VSSQ), U1.12 (VSSQ), U1.28 (VSS), U1.41 (VSS), U1.46 (VSSQ), U1.52 (VSSQ), U1.54 (VSS), U2.A1 (GND), U2.A11 (GND), U2.B8 (GND), U2.C5 (GND), U2.C15 (GND), U2.D2 (GND)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
unnamed: D8.2 (A), R48.2
unnamed: J1.A5 (CC1), R10.1
unnamed: J1.B5 (CC2), R19.1
unnamed: J3.9 (DET_B), R38.2
unnamed: R13.2, U3.1 (VIN)
unnamed: C11.2, R8.2, R9.1, U4.6 (FB)
unnamed: L2.1, U4.3 (SW)
unnamed: C58.2, R61.2, R62.1, U9.6 (FB)
unnamed: L3.1, U9.3 (SW)

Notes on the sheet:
K I R S C H
0.6 * (1 + (200/44.2)) = 3.31
0.6 * (1 + (100/150)) = 0.999
MASTER SPI MODE (001)

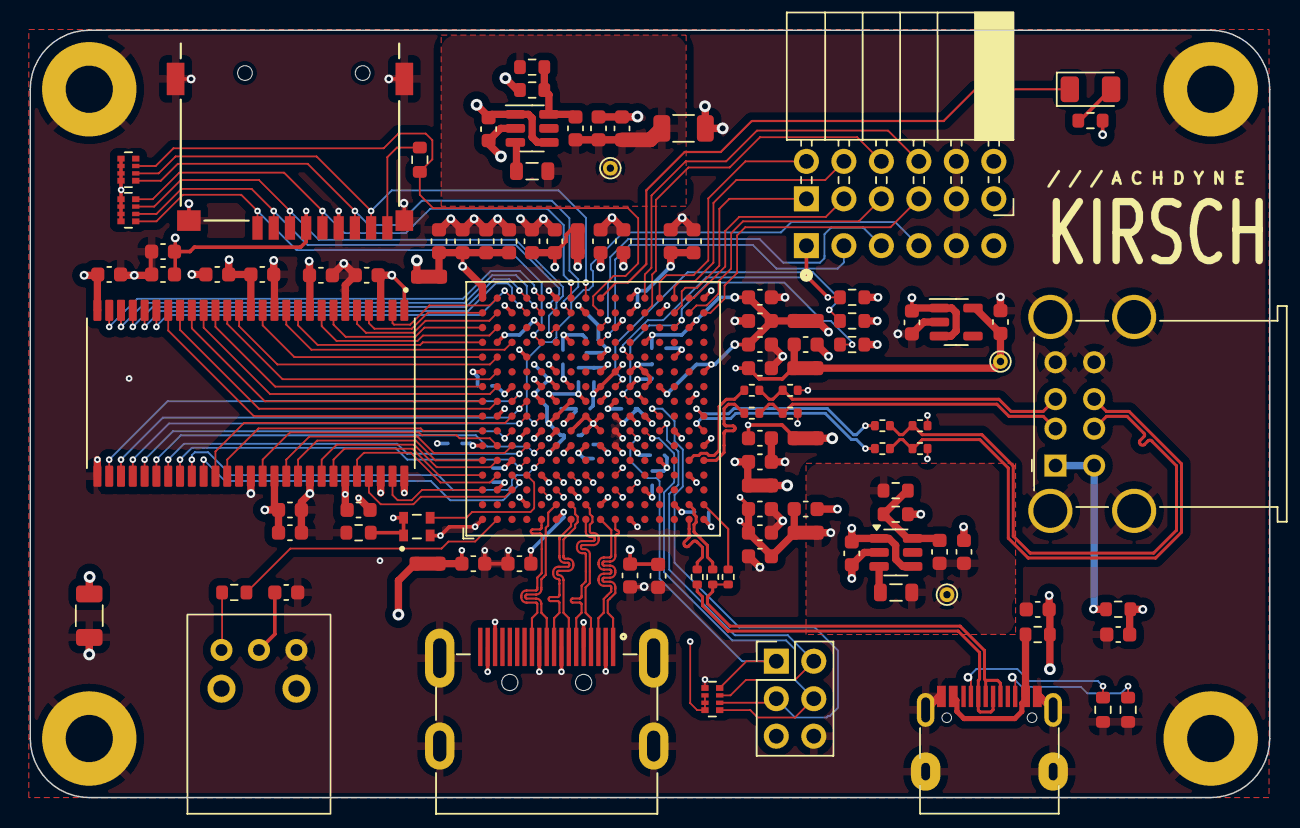
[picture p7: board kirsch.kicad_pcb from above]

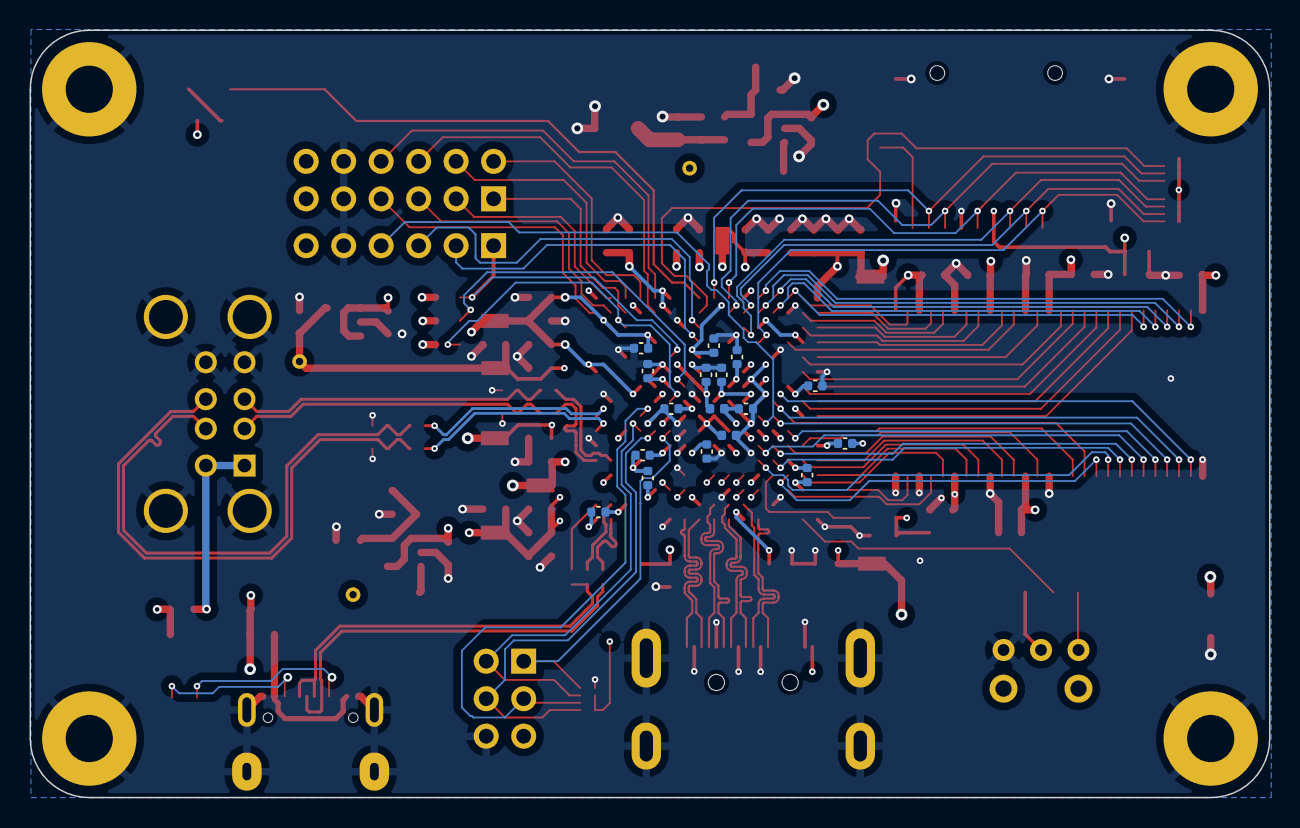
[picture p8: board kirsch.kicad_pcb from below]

Board: 4 copper layers, 84.0 x 52.0 mm, 127 parts (17 on the bottom side), 114 nets.

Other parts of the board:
R20: 2K2; R_0603_1608Metric

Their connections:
/CSPI_SS: R20.2; also elsewhere on the board
/PWR3V3: R20.1; also elsewhere on the board

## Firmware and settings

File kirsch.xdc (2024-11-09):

################################################################################
# IO constraints
################################################################################
# clk48:0
set_property LOC D4 [get_ports {clk48}]
set_property IOSTANDARD LVCMOS33 [get_ports {clk48}]

# led:0
set_property LOC J16 [get_ports {led}]
set_property IOSTANDARD LVCMOS33 [get_ports {led}]

# sys_rst_n:0
set_property LOC P14 [get_ports {sys_rst_n}]
set_property IOSTANDARD LVCMOS33 [get_ports {sys_rst_n}]

# aud_optical:0
set_property LOC B1 [get_ports {aud_optical}]
set_property IOSTANDARD LVCMOS33 [get_ports {aud_optical}]

# pmod_a1:0
set_property LOC P15 [get_ports {pmod_a1}]
set_property IOSTANDARD LVCMOS33 [get_ports {pmod_a1}]

# pmod_a2:0
set_property LOC R16 [get_ports {pmod_a2}]
set_property IOSTANDARD LVCMOS33 [get_ports {pmod_a2}]

# pmod_a3:0
set_property LOC R15 [get_ports {pmod_a3}]
set_property IOSTANDARD LVCMOS33 [get_ports {pmod_a3}]

# pmod_a4:0
set_property LOC T15 [get_ports {pmod_a4}]
set_property IOSTANDARD LVCMOS33 [get_ports {pmod_a4}]

# pmod_a7:0
set_property LOC N16 [get_ports {pmod_a7}]
set_property IOSTANDARD LVCMOS33 [get_ports {pmod_a7}]

# pmod_a8:0
set_property LOC P16 [get_ports {pmod_a8}]
set_property IOSTANDARD LVCMOS33 [get_ports {pmod_a8}]

# pmod_a9:0
set_property LOC M15 [get_ports {pmod_a9}]
set_property IOSTANDARD LVCMOS33 [get_ports {pmod_a9}]

# pmod_a10:0
set_property LOC M16 [get_ports {pmod_a10}]
set_property IOSTANDARD LVCMOS33 [get_ports {pmod_a10}]

# sdram_clock:0
set_property LOC C8 [get_ports {sdram_clock}]
set_property IOSTANDARD LVTTL [get_ports {sdram_clock}]

# serial:0.tx
set_property LOC R16 [get_ports {serial_tx}]
set_property IOSTANDARD LVCMOS33 [get_ports {serial_tx}]

# serial:0.rx
set_property LOC R15 [get_ports {serial_rx}]
set_property IOSTANDARD LVCMOS33 [get_ports {serial_rx}]

# sdram:0.a
set_property LOC D15 [get_ports {sdram_a[0]}]
set_property IOSTANDARD LVTTL [get_ports {sdram_a[0]}]

# sdram:0.a
set_property LOC D16 [get_ports {sdram_a[1]}]
set_property IOSTANDARD LVTTL [get_ports {sdram_a[1]}]

# sdram:0.a
set_property LOC E15 [get_ports {sdram_a[2]}]
set_property IOSTANDARD LVTTL [get_ports {sdram_a[2]}]

# sdram:0.a
set_property LOC E16 [get_ports {sdram_a[3]}]
set_property IOSTANDARD LVTTL [get_ports {sdram_a[3]}]

# sdram:0.a
set_property LOC C9 [get_ports {sdram_a[4]}]
set_property IOSTANDARD LVTTL [get_ports {sdram_a[4]}]

# sdram:0.a
set_property LOC D9 [get_ports {sdram_a[5]}]
set_property IOSTANDARD LVTTL [get_ports {sdram_a[5]}]

# sdram:0.a
set_property LOC D8 [get_ports {sdram_a[6]}]
set_property IOSTANDARD LVTTL [get_ports {sdram_a[6]}]

# sdram:0.a
set_property LOC C7 [get_ports {sdram_a[7]}]
set_property IOSTANDARD LVTTL [get_ports {sdram_a[7]}]

# sdram:0.a
set_property LOC E6 [get_ports {sdram_a[8]}]
set_property IOSTANDARD LVTTL [get_ports {sdram_a[8]}]

# sdram:0.a
set_property LOC D6 [get_ports {sdram_a[9]}]
set_property IOSTANDARD LVTTL [get_ports {sdram_a[9]}]

# sdram:0.a
set_property LOC C16 [get_ports {sdram_a[10]}]
set_property IOSTANDARD LVTTL [get_ports {sdram_a[10]}]

# sdram:0.a
set_property LOC D5 [get_ports {sdram_a[11]}]
set_property IOSTANDARD LVTTL [get_ports {sdram_a[11]}]

# sdram:0.a
set_property LOC E5 [get_ports {sdram_a[12]}]
set_property IOSTANDARD LVTTL [get_ports {sdram_a[12]}]

# sdram:0.ba
set_property LOC B9 [get_ports {sdram_ba[0]}]
set_property IOSTANDARD LVTTL [get_ports {sdram_ba[0]}]

# sdram:0.ba
set_property LOC A8 [get_ports {sdram_ba[1]}]
set_property IOSTANDARD LVTTL [get_ports {sdram_ba[1]}]

# sdram:0.cs_n
set_property LOC A9 [get_ports {sdram_cs_n}]
set_property IOSTANDARD LVTTL [get_ports {sdram_cs_n}]

# sdram:0.cke
set_property LOC C4 [get_ports {sdram_cke}]
set_property IOSTANDARD LVTTL [get_ports {sdram_cke}]

# sdram:0.ras_n
set_property LOC B10 [get_ports {sdram_ras_n}]
set_property IOSTANDARD LVTTL [get_ports {sdram_ras_n}]

# sdram:0.cas_n
set_property LOC A10 [get_ports {sdram_cas_n}]
set_property IOSTANDARD LVTTL [get_ports {sdram_cas_n}]

# sdram:0.we_n
set_property LOC B11 [get_ports {sdram_we_n}]
set_property IOSTANDARD LVTTL [get_ports {sdram_we_n}]

# sdram:0.dq
set_property LOC B16 [get_ports {sdram_dq[0]}]
set_property IOSTANDARD LVTTL [get_ports {sdram_dq[0]}]

# sdram:0.dq
set_property LOC A15 [get_ports {sdram_dq[1]}]
set_property IOSTANDARD LVTTL [get_ports {sdram_dq[1]}]

# sdram:0.dq
set_property LOC B15 [get_ports {sdram_dq[2]}]
set_property IOSTANDARD LVTTL [get_ports {sdram_dq[2]}]

# sdram:0.dq
set_property LOC A14 [get_ports {sdram_dq[3]}]
set_property IOSTANDARD LVTTL [get_ports {sdram_dq[3]}]

# sdram:0.dq
set_property LOC B14 [get_ports {sdram_dq[4]}]
set_property IOSTANDARD LVTTL [get_ports {sdram_dq[4]}]

# sdram:0.dq
set_property LOC A13 [get_ports {sdram_dq[5]}]
set_property IOSTANDARD LVTTL [get_ports {sdram_dq[5]}]

# sdram:0.dq
set_property LOC C13 [get_ports {sdram_dq[6]}]
set_property IOSTANDARD LVTTL [get_ports {sdram_dq[6]}]
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

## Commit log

2024-11-08 add schematics
2024-11-09 add case
    [kirsch.scad]
2024-11-09 update case
    [kirsch.scad]
2026-09-12 add pcb
    [kirsch.kicad_pcb, kirsch.kicad_sch]

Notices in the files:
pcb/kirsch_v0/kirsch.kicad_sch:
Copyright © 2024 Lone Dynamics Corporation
